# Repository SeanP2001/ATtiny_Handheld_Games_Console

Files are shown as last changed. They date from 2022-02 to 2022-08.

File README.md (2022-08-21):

# ATtiny Handheld Games Console

## Table of Contents

- [Introduction](#introduction)
- [Circuitry](#circuitry)
  * [Schematic](#schematic)
  * [PCB Design](#pcb-design)
    + [Button Footprints](#button-footprints)
    + [Display Pinout Jumpers](#display-pinout-jumpers)
  * [Soldered PCB](#soldered-pcb)
- [Board Manager & Programming Setup](#board-manager---programming-setup)
- [Code](#code)
- [Enclosure](#enclosure)
  * [CAD Enclosure](#cad-enclosure)
  * [3D Printed Enclosure](#3d-printed-enclosure)
- [Game Library](#game-library)
- [Further Work](#further-work)
  * [Version 2 - Featuring the Pico](#version-2---featuring-the-pico)

## Introduction

My aim is to create a handheld games console, based on the ATtiny85 AVR microcontroller. Users will be able to program their own games and play them anywhere. The long-term goal for this project is to create a library of games, and it would be amazing to build a community of users who can upload their games for others to download and play.

## Circuitry

### Schematic

<p align="center">
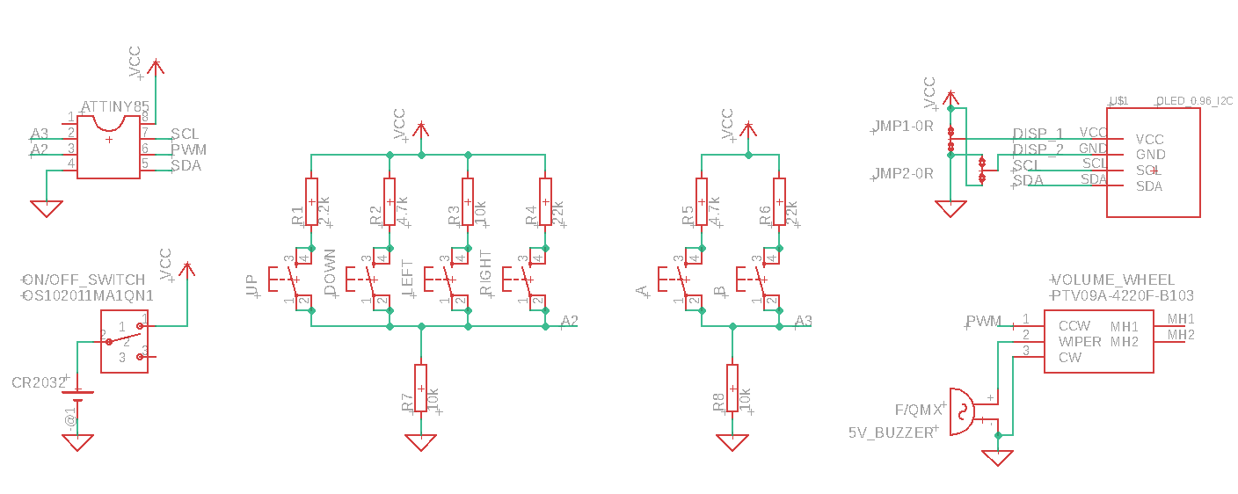
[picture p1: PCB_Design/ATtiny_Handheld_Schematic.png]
 
</p>

### PCB Design

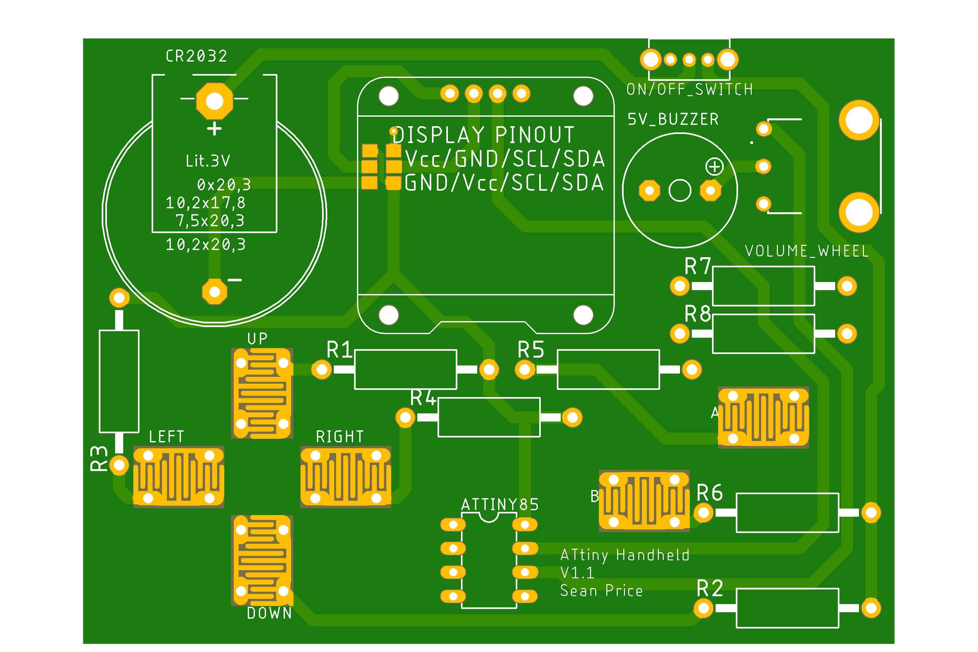
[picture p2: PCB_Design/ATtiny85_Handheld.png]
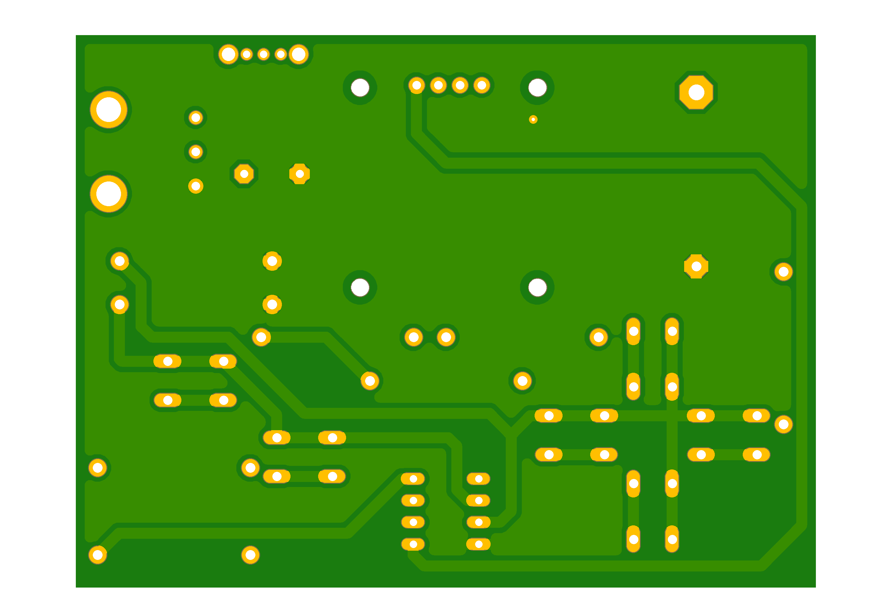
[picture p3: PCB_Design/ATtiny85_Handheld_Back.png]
|  |  |
| --- | --- |
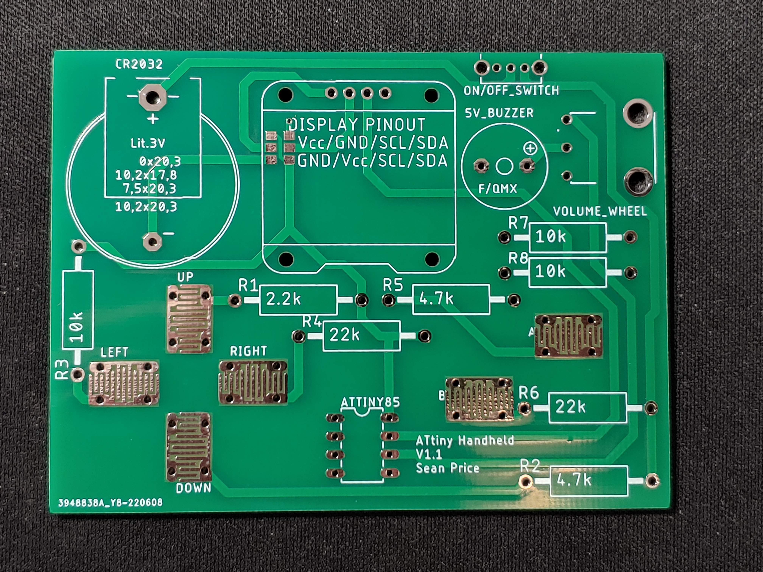
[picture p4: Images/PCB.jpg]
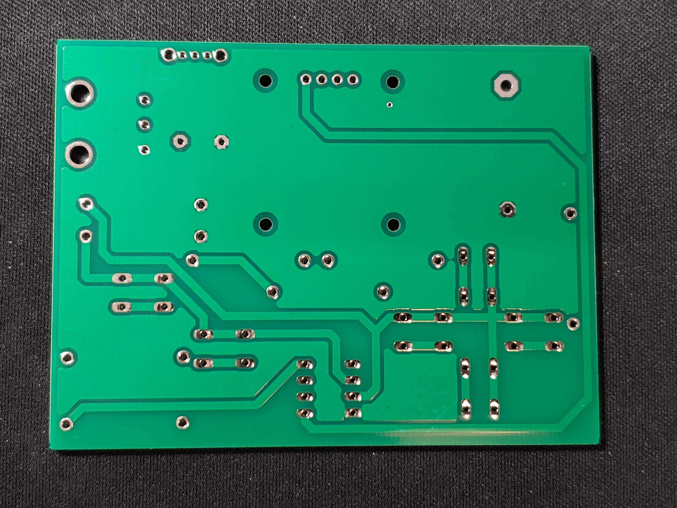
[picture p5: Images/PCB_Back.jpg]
|  |  |

#### Button Footprints

I designed the button footprint to give the option of using either tactile buttons or silicone button membranes. However, after experimenting I have found that silicone buttons will never work with this design. The analog value recieved by the microcontroller varies wildly depending on the pressure applied to the button. This makes silicone buttons unusable. **Please use tactile buttons when assembling the PCB**. In the next PCB revision, I intend to remove the contact pads and return to a regular tactile button footprint.

#### Display Pinout Jumpers

Another feature of the PCB is the jumper connections under the display. The I2C OLED displays do not all have the same pin layout. When you buy a display online, the item you recieve may not have the same pinout as the one in the photos. Due to this inconsistency I have designed the board to work with both pinouts. If your display has the pinout (in order) Vcc/GND/SCL/SDA then you need to use solder to bridge the middle pads to the upper pads (shown blue below). If it is GND/Vcc/SCL/SDA then you need to bridge the middle pads to the lower pads (shown red below). Once you have done this, use Kapton tape to insulate the solder bridges and prevent them from causing a short circuit on the back of the display.

<p align="center">
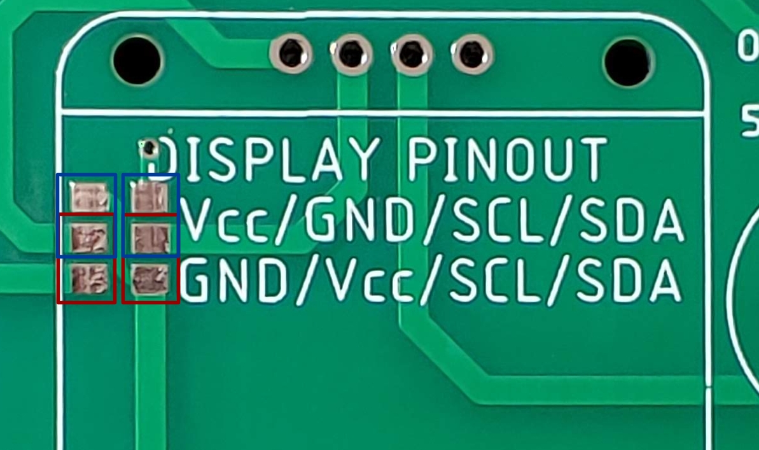
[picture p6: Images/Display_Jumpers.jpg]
 
</p>

### Soldered PCB

<p align="center">
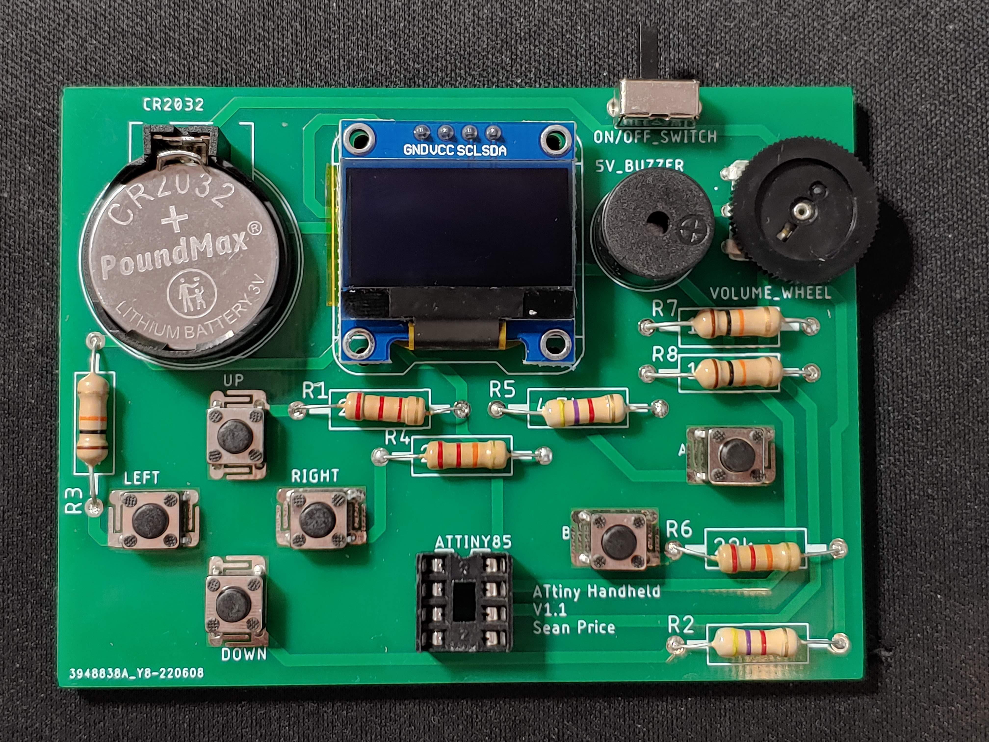
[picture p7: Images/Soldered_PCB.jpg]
 
</p>

## Board Manager & Programming Setup

I am using the ATTinyCore board manager ([GitHub - SpenceKonde/ATTinyCore: Arduino core for ATtiny 1634, 828, x313, x4, x41, x5, x61, x7 and x8](https://github.com/SpenceKonde/ATTinyCore)) with the following settings:

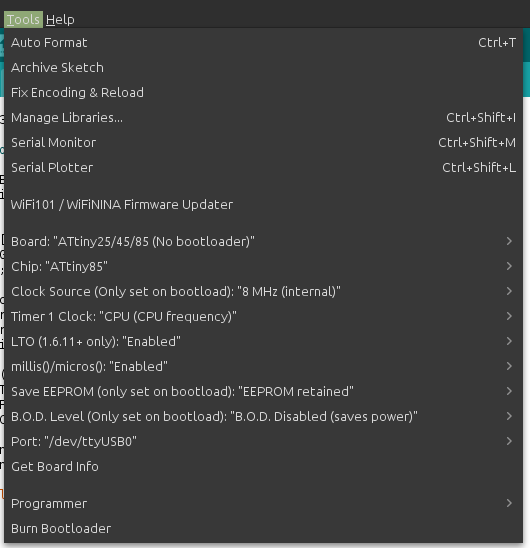
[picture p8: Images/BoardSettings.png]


Currently I am programming the ATtiny using an Arduino Uno as a programmer. You could either do this or use a dedicated ISP programmer.

## Code

This repostitory includes code to test that the buttons and display are working correctly. When you press a button the display should show the analog value on the actionButton and directionButton pins, along with the name of the button pressed. Recognised buttons are as follows:

- UP

- DOWN

- LEFT

- RIGHT

- UP_LEFT

- UP_RIGHT

- DOWN_LEFT

- DOWN_RIGHT

- A

- B
  
  <p align="center">
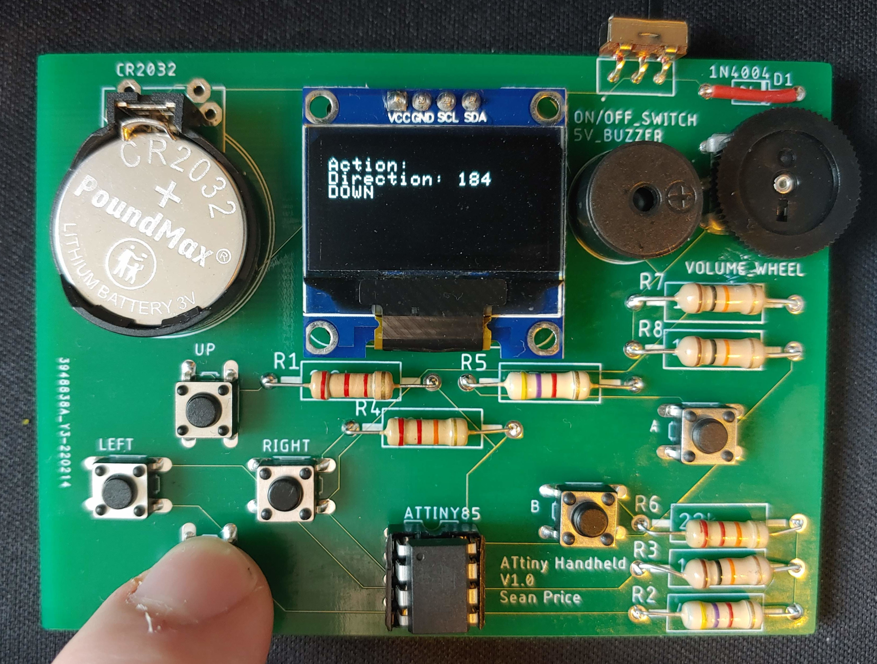
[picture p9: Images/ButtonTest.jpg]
  
  </p>

## Enclosure

### CAD Enclosure

<p align="center">
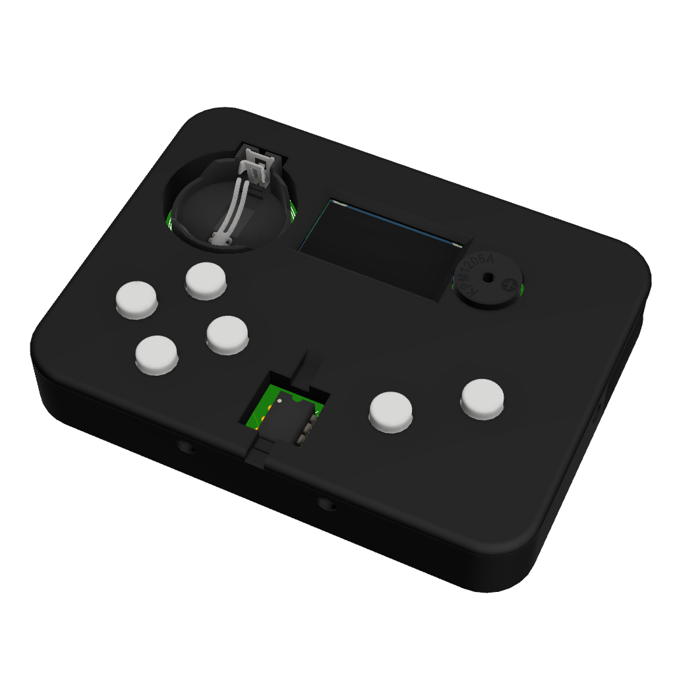
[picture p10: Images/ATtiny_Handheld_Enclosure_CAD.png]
  
  </p>

### 3D Printed Enclosure

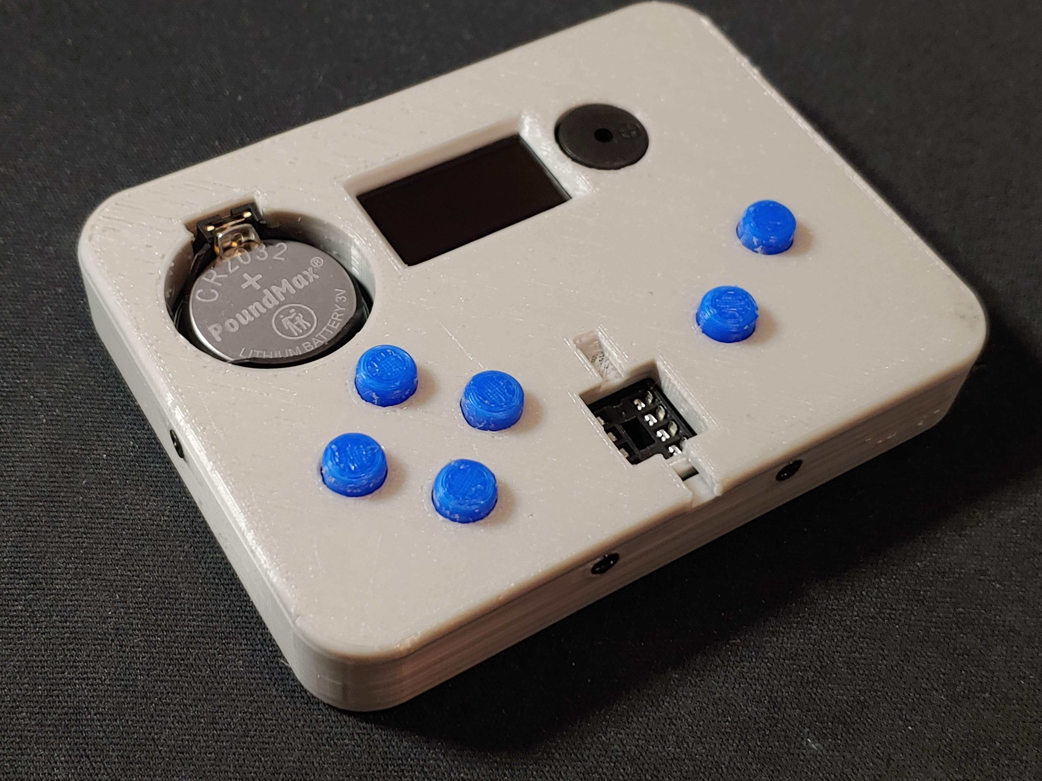
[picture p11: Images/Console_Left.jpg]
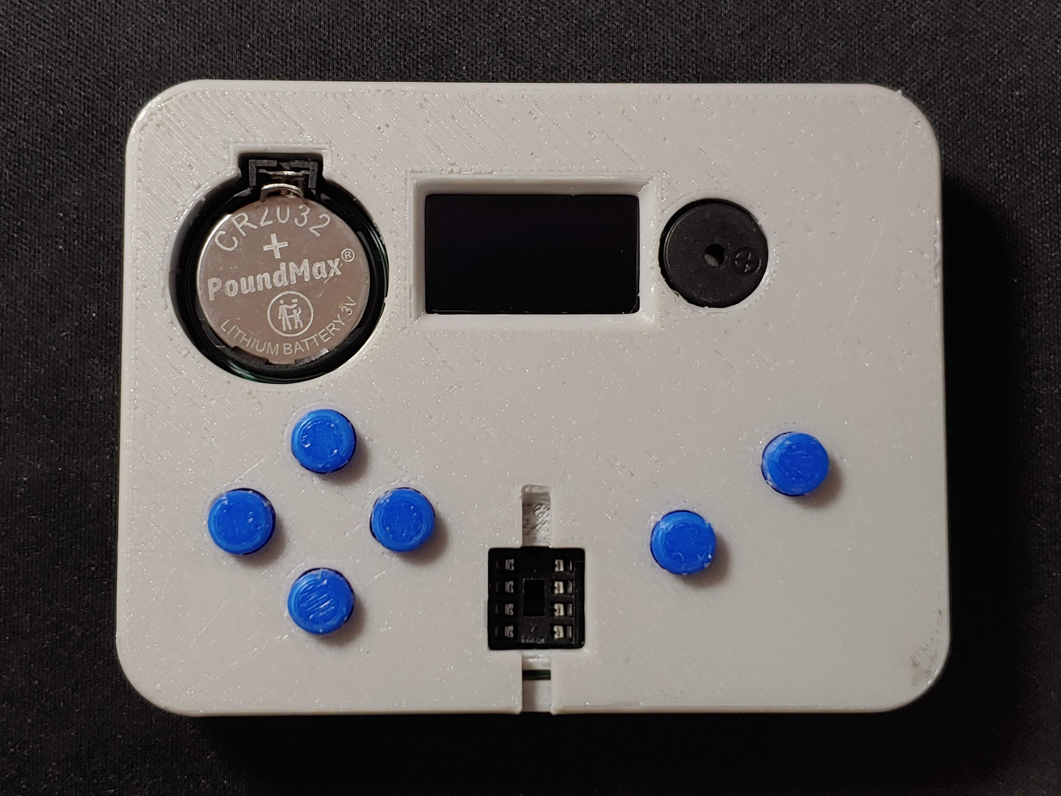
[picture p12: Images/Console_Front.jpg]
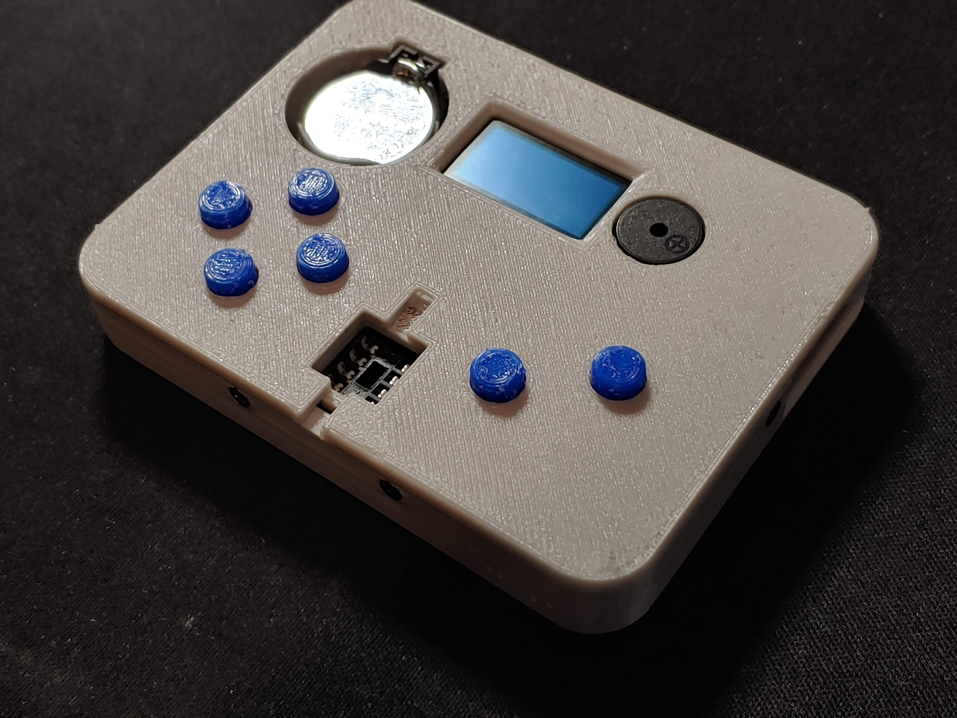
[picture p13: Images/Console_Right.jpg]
|  |  |  |
| --- | --- | --- |

## Game Library

This is where you can find all of the games made for the console.

- [Astro Barrier](https://github.com/SeanP2001/ATtiny_Astro_Barrier)
- [Snake](https://github.com/SeanP2001/ATtiny_Snake)

## Further Work

Next time I order PCBs I will remove the contact pads and return to a regular tactile button footprint. I will also remove the silicone button membranes and alignment pins from the enclosure design. I may make small alterations to the height of the buttons along with minimising the gaps around the volume wheel and on/off switch.

### Version 2 - Featuring the Pico

I have realised that this project is not as accessible as I would like. Programming an ATtiny could be a complicated and off-putting task for a beginner. The initial goal of this project was to make a platform for people to practice programming. 

To make a more accessible platform I think I need to switch to using a USB programmable board. An ideal candidate for this is the Raspberry Pi Pico because you can just plug it into your computer and program it using MicroPython or C++. 

However, using the Pico brings it's own challenges. For instance:

- Not all Arduino libraries are compatible (might be fixable with a compatability layer)

- A coin cell battery will no longer be adequate

- You cannot change games without re-programming the board

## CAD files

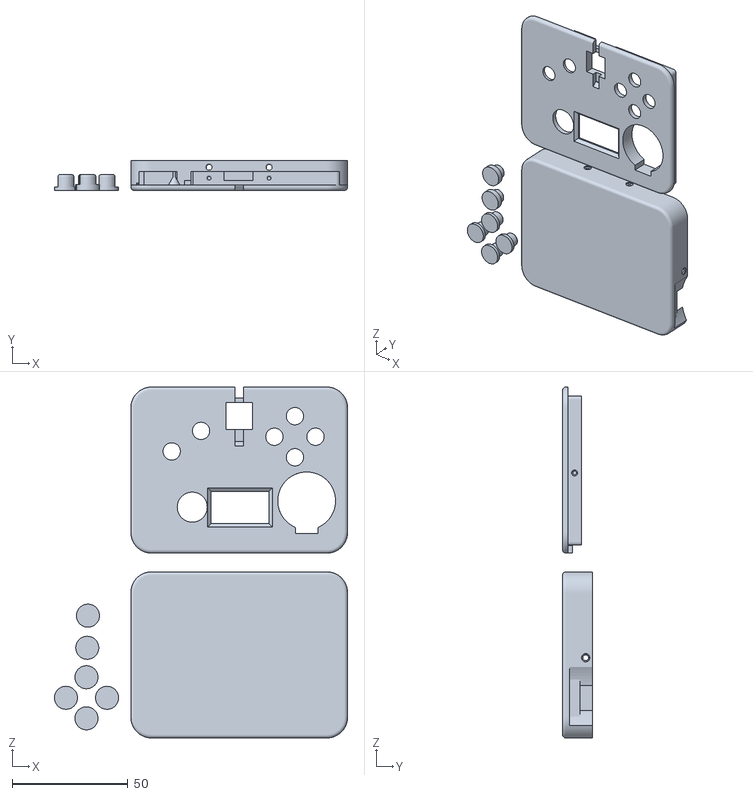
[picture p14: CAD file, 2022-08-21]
Enclosure/ATtiny_Handheld_Enclosure_Printable.stl
126.9 x 13.0 x 151.9

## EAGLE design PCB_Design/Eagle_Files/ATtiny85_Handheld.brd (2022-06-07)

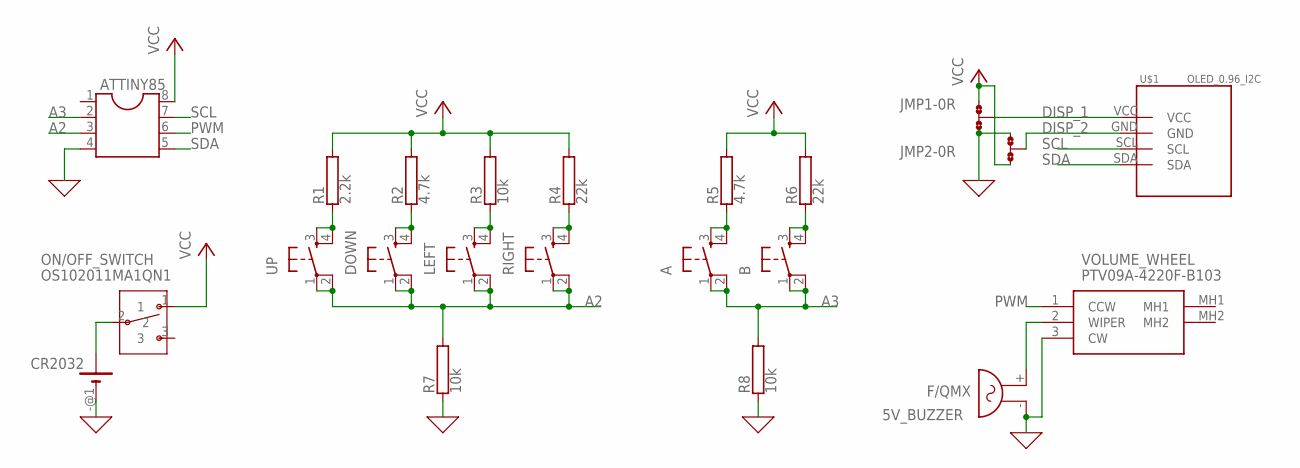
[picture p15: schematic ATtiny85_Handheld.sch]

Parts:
5V_BUZZER: F/QMX
A: TACTILE/SILICONE_BUTTON
ATTINY85: DIL8; DIL08
B: TACTILE/SILICONE_BUTTON
CR2032: CR2032_BATTERY_HOLDER
DOWN: TACTILE/SILICONE_BUTTON
JMP1, JMP2: 0R-JUMPA; A0R-JMP
LEFT: TACTILE/SILICONE_BUTTON
ON/OFF_SWITCH: OS102011MA1QN1
R1: 2.2k; AC01
R2, R5: 4.7k; AC01
R3, R7, R8: 10k; AC01
R4, R6: 22k; AC01
RIGHT: TACTILE/SILICONE_BUTTON
U$1: OLED_0.96_I2C
UP: TACTILE/SILICONE_BUTTON
VOLUME_WHEEL: PTV09A-4220F-B103; PTV09A4220FB103

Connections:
A2: ATTINY85.3, DOWN.1, DOWN.2 (P1), LEFT.1, LEFT.2 (P1), R7.2, RIGHT.1, RIGHT.2 (P1), UP.1, UP.2 (P1)
A3: A.1, A.2 (P1), ATTINY85.2, B.1, B.2 (P1), R8.2
DISP_1: JMP1.2, U$1.VCC
DISP_2: JMP2.2, U$1.GND
GND: 5V_BUZZER.- (1), ATTINY85.4, CR2032.-@1 (-), JMP1.3, JMP2.1, R7.1, R8.1, VOLUME_WHEEL.3 (CW)
unnamed: CR2032.+@4 (+), ON/OFF_SWITCH.2
unnamed: R4.1, RIGHT.3 (S), RIGHT.4 (S1)
unnamed: LEFT.3 (S), LEFT.4 (S1), R3.1
unnamed: DOWN.3 (S), DOWN.4 (S1), R2.1
unnamed: R1.1, UP.3 (S), UP.4 (S1)
unnamed: A.3 (S), A.4 (S1), R5.1
unnamed: B.3 (S), B.4 (S1), R6.1
unnamed: 5V_BUZZER.+ (2), VOLUME_WHEEL.2 (WIPER)
PWM: ATTINY85.6, VOLUME_WHEEL.1 (CCW)
SCL: ATTINY85.7, U$1.SCL
SDA: ATTINY85.5, U$1.SDA
VCC: ATTINY85.8, JMP1.1, JMP2.3, ON/OFF_SWITCH.1, R1.2, R2.2, R3.2, R4.2, R5.2, R6.2

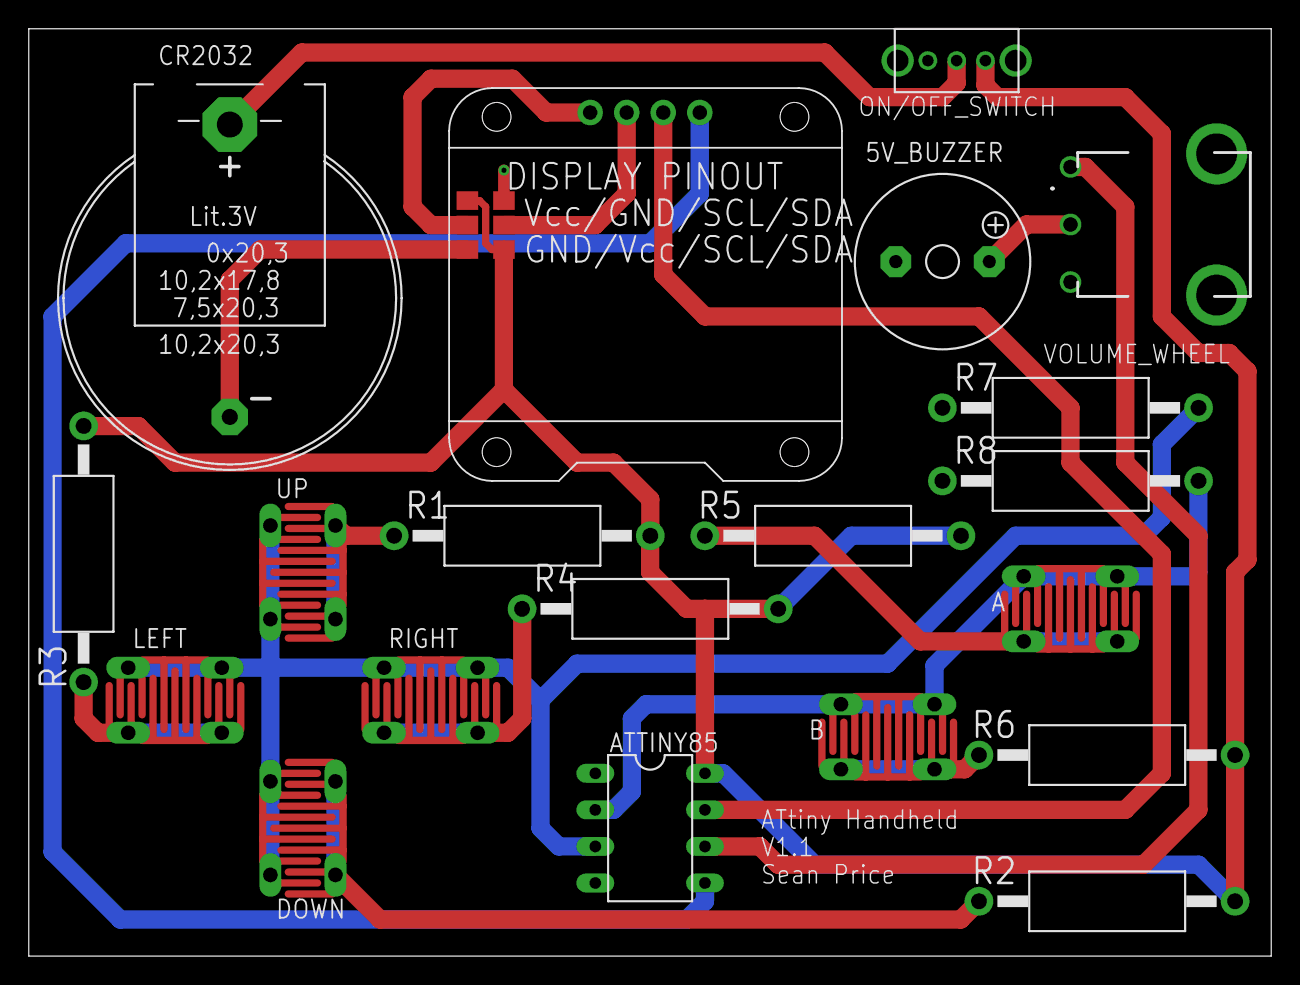
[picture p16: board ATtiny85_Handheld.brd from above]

Board: 2 copper layers, 86.3 x 64.4 mm, 22 parts (0 on the bottom side), 17 nets.

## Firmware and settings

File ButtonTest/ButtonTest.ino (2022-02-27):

#include <SSD1306_minimal.h>

#include "Button.h"

#define actionButtons A3
#define directionButtons A2

uint8_t action = 0;
char actionStr[3];
uint8_t dir = 0;
char dirStr[3];

Button UP(directionButtons, 67, 78);
Button DOWN(directionButtons, 150, 200);
Button LEFT(directionButtons, 230, 255);
Button RIGHT(directionButtons, 50, 67);

Button UP_LEFT(directionButtons, 93, 150);
Button UP_RIGHT(directionButtons, 78, 93);
Button DOWN_LEFT(directionButtons, 6, 49);
Button DOWN_RIGHT(directionButtons, 200, 230);

Button A(actionButtons, 125, 255);
Button B(actionButtons, 20, 125);

SSD1306_Mini oled;

 

void setup() {
  oled.init(0x3C);
}

void loop() {

  action = analogRead(actionButtons);
  sprintf(actionStr, "%i",action);
  dir = analogRead(directionButtons);
  sprintf(dirStr, "%i",dir);

  oled.clear();
  
  oled.cursorTo(0, 1);
  oled.printString("Action: ");
  oled.printString(actionStr);
  
  oled.cursorTo(0, 2);
  oled.printString("Direction: ");
  oled.printString(dirStr);

  oled.cursorTo(0, 3);
  
  if (UP.isPressed())
    oled.printString("UP");
  if (DOWN.isPressed())
    oled.printString("DOWN");
  if (LEFT.isPressed())
    oled.printString("LEFT");
  if (RIGHT.isPressed())
    oled.printString("RIGHT");

  if (UP_LEFT.isPressed())
    oled.printString("UP_LEFT");
  if (UP_RIGHT.isPressed())
    oled.printString("UP_RIGHT");
  if (DOWN_LEFT.isPressed())
    oled.printString("DOWN_LEFT");
  if (DOWN_RIGHT.isPressed())
    oled.printString("DOWN_RIGHT");

  if (A.isPressed())
    oled.printString("A");
  if (B.isPressed())
    oled.printString("B");
  
  delay(500);
}

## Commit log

2022-02-27 V0.1.0 Added PCB files, code to test the PCB and updated README.md
    [ATtiny85_Handheld.brd, ATtiny85_Handheld.sch]
2022-03-13 V0.2.0 Created 3D model of the populated PCB
    [0.96 OLED v3.step, ATtiny85_Handheld.brd, ATtiny85_Handheld.sch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]
2022-03-20 V1.0.0 Added enclosure CAD files and updated README.md
    [ATtiny_Handheld_Enclosure_Printable.stl]
2022-06-02 V1.2.0 Updated the PCB to V1.1
    - Option of using silicone or tactile buttons
    - Removed D1
    - Hand-router, thicker traces
    - Broke the schematic into sections to make it easier to follow
    - Update/fixed the battery holder footprint
    - Changed the switch footprint to use an angled slide switch
    [ATtiny85_Handheld.brd, ATtiny85_Handheld.sch]
2022-06-07 Finalised PCB V1.1
    [ATtiny85_Handheld.brd, ATtiny85_Handheld.sch]
2022-06-07 V1.2.1 Finalised PCB V1.1
    [ATtiny85_Handheld.brd, ATtiny85_Handheld.sch]
2022-08-21 V1.3.0 Updated the enclosure to fit PCB V1.1
    - Choice between using tactile or silicone buttons (both STL files available)
    [ATtiny_Handheld_Enclosure_Printable.stl, ATtiny_Handheld_Enclosure_Printable_(Silicone).stl, ATtiny_Handheld_Enclosure_Printable_(Tactile).stl]
2022-08-21 V1.3.1 Fixed left button not being recognised
2022-08-21 V1.4.0 Updated README.md
    [ATtiny_Handheld_Enclosure_Printable.stl, ATtiny_Handheld_Enclosure_Printable_(Silicone).stl]
2022-09-05 V1.4.1 Removed Old PCB 3D Files
